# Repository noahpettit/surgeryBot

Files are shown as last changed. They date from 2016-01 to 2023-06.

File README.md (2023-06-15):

# surgeryBot
Code for motorized control of kopf 1900 stereotaxic  

key features:
- easily removable for cleaning / autoclaving
- adjustable gear ratio with simple, friction-fit parts
- even with motor mounted and gears engaged, you can still move stereotax manually (unlike some other motorized sterotaxes). 
- stepper is self-calibrating based on encoder feedback
- ~1um accuracy (same as encoder readout)
- closed-loop control using either computer and/or microcontroller
- matlab library for easy integration into more complex control programs (such as automated surgery bot).

# Hardware
The basic hardware consists of a laser-cut mount(s) to drive one or more axes with nema 17 stepper motors.






## Stepper Motor Mount


Mount hardware laser cut from 1/4" acrylic. The gears that fit onto the knob are friction fit so adjust the internal diameter if neccessary (or add tape/ shim) to get a tight fit so that they don't slip. 

laser-cutter ready designs in https://github.com/noahpettit/surgeryBot/blob/master/Hardware/Stepper_mount/StepperMountAndGears_v2_lasercutter.pdf 

I think all screws are M3, so non-through holes need to be M3 tapped.

## Stepper motor

I believe I used this one: https://www.adafruit.com/product/324
Although slightly more powerful motors would probably be better, especially if your axis is a bit sticky. 

## Stepper motor driver

I used this: https://www.adafruit.com/product/1438 with an arduino uno. It needs to have its own power source that provides enough current to drive whatever steppers you are using. I also STRONGLY suggest having an inline power switch so that you can quickly turn off the system if something goes wrong. The last thing you want is for a bug in your code to cause the stepper motor to drive the arm too fast or beyond its limits and potentially damage it. If using long-term, consider incorporating limit switches.

## Cables
 - computer to arduino USB
 - power cable for stepper motor driver
 - wires to connect stepper with stepper motor driver
 - serial to serial or serial to USB to connect accurite with computer and get position read-out

# Software

The basic idea is thatyou initialize a matlab surgery object that handles communication with the hardware (through serial communication). it reads in position data from the accurite and directs the stepper to move forwards or backwards. 
The object can self-calibrate using encoder feedback to get um per step of the stepper, and then also operates in closed-loop during execution to ensure that targets are reached and not exceeded. 

Test all the code yourself and use at your own risk! 

Using that object as a simple interface with the harware, you can write matlab scripts that contain cells that you might execute during particular stages of your surgery (see Protocols folder for an example).

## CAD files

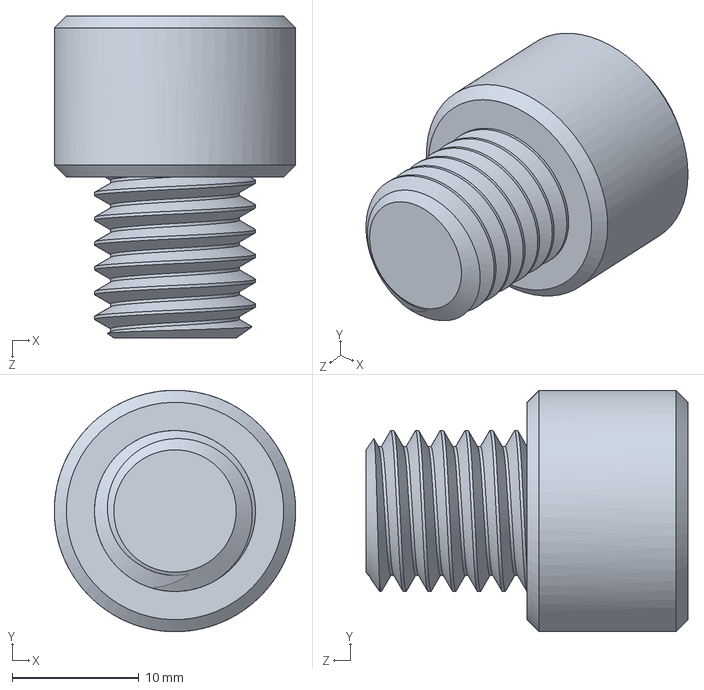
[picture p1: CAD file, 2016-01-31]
95868A407.SLDPRT
19.1 x 19.0 x 25.4 mm

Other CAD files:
Hardware/Stepper_mount/cameraMount_USBPluggableKopf.dwg
Hardware/Stepper_mount/stereotax_stepperMount3.dwg
Hardware/Stepper_mount/usbCameraMount2.dwg
Hardware/Stepper_mount/cameraMount_BaslerKopf.dwg
Hardware/Stepper_mount/stereotax_gearMount4_gearKerfAdjusted.dwg
Hardware/Stepper_mount/stereotax_stepperMount3_1_1648782924_7599.sv$.dwg
Hardware/Stepper_mount/stereotax_gearMount2.dwg
Hardware/Stepper_mount/stereotax_gearMount4.dwg
Hardware/Stepper_mount/stereotax_stepperMount2.dwg
Hardware/Stepper_mount/stereotax_gearMount3.dwg
Hardware/Stepper_mount/usbCameraMount3.dwg
Hardware/Stepper_mount/stereotax_gearMount2_1_446280268_4971.sv$.dwg
Hardware/Stepper_mount/stereotax_gearMount.dwg
Hardware/Stepper_mount/stereotax_stepperMount.dwg
Hardware/Stepper_mount/StepperMountAndGears_v2.dwg
Hardware/Stepper_mount/gear.iam

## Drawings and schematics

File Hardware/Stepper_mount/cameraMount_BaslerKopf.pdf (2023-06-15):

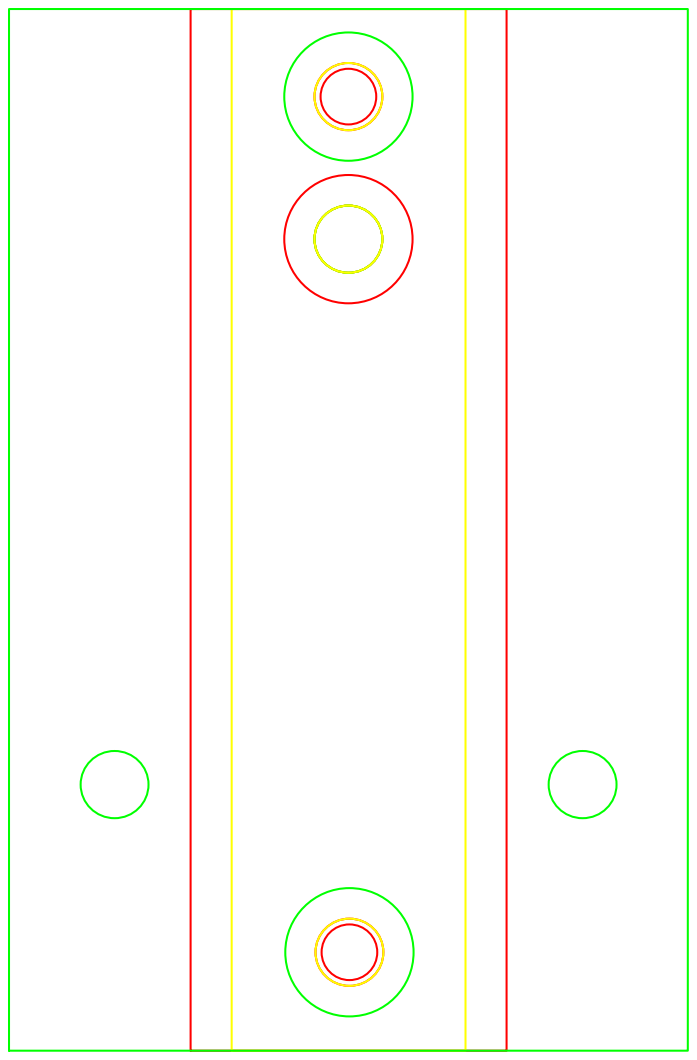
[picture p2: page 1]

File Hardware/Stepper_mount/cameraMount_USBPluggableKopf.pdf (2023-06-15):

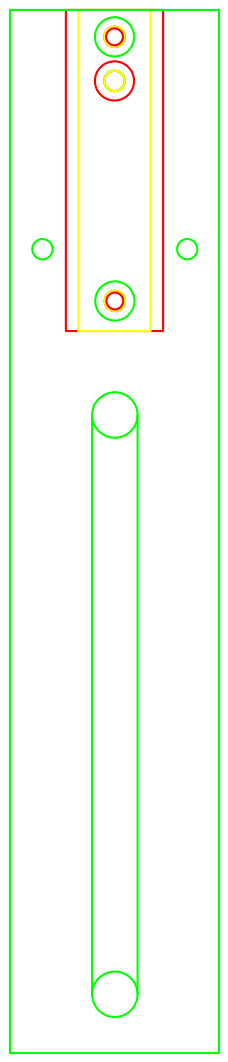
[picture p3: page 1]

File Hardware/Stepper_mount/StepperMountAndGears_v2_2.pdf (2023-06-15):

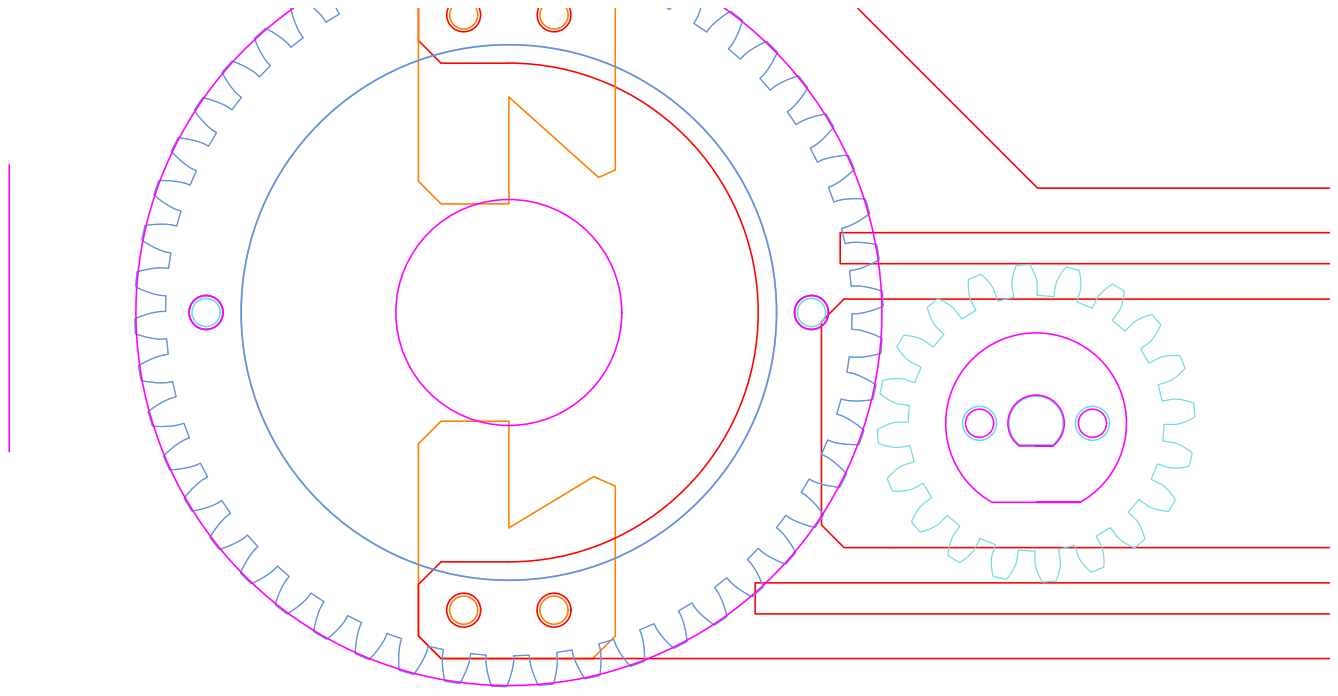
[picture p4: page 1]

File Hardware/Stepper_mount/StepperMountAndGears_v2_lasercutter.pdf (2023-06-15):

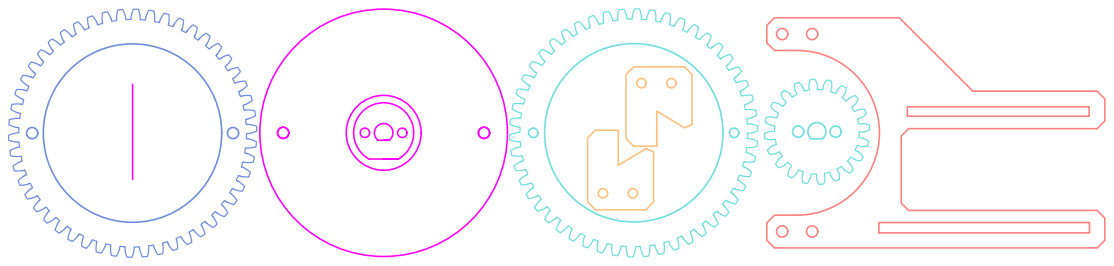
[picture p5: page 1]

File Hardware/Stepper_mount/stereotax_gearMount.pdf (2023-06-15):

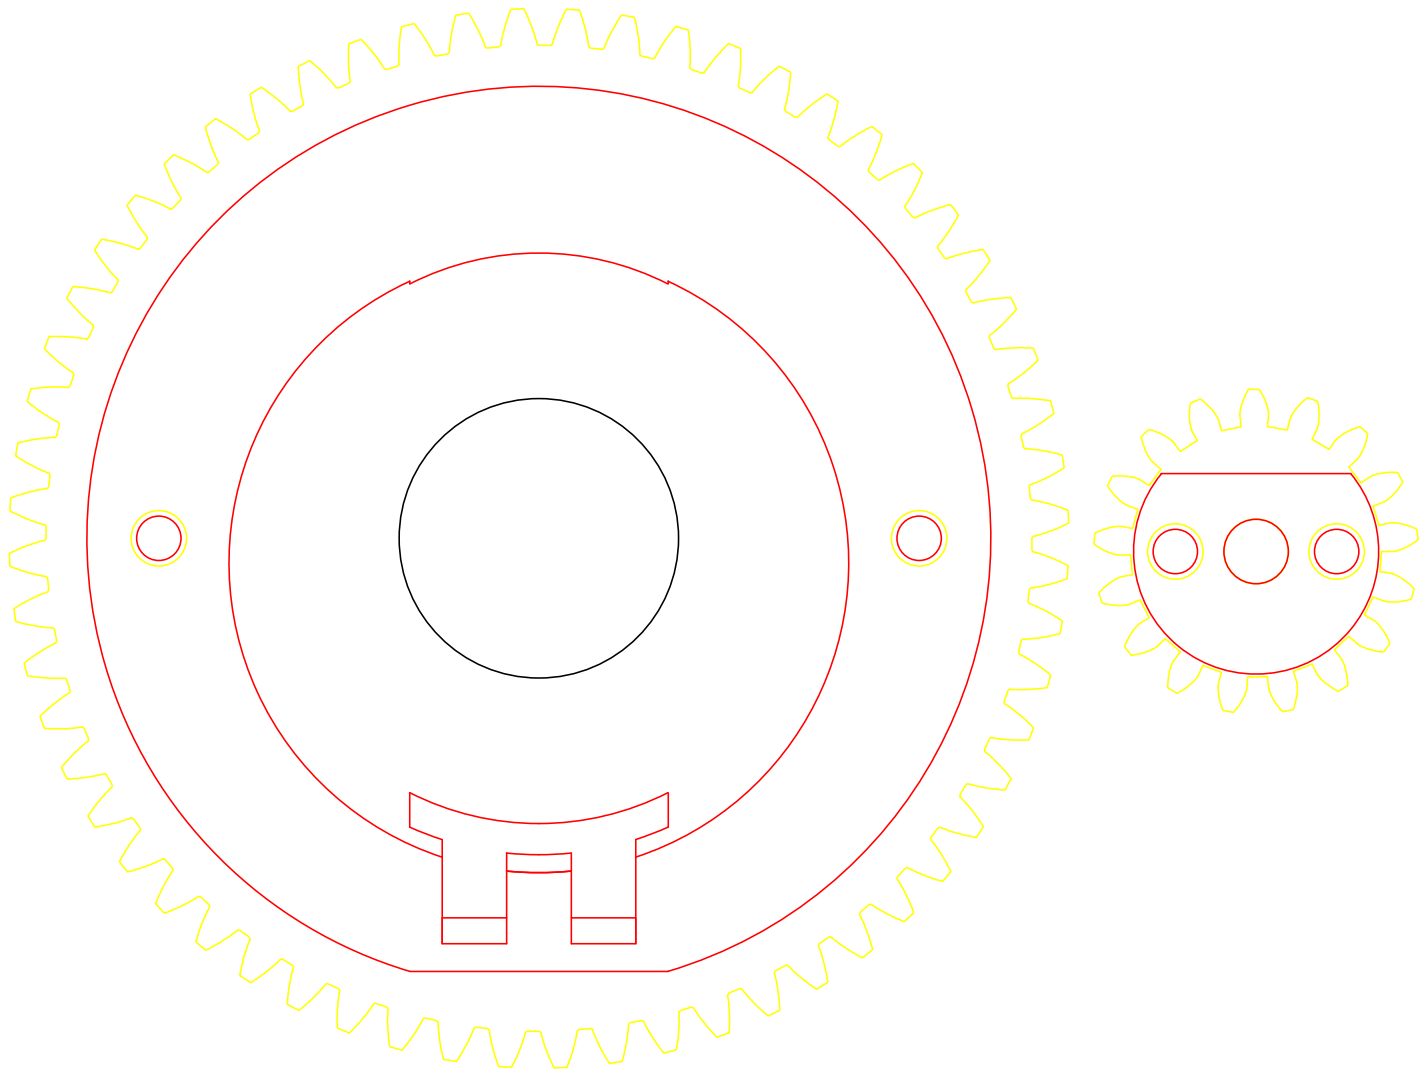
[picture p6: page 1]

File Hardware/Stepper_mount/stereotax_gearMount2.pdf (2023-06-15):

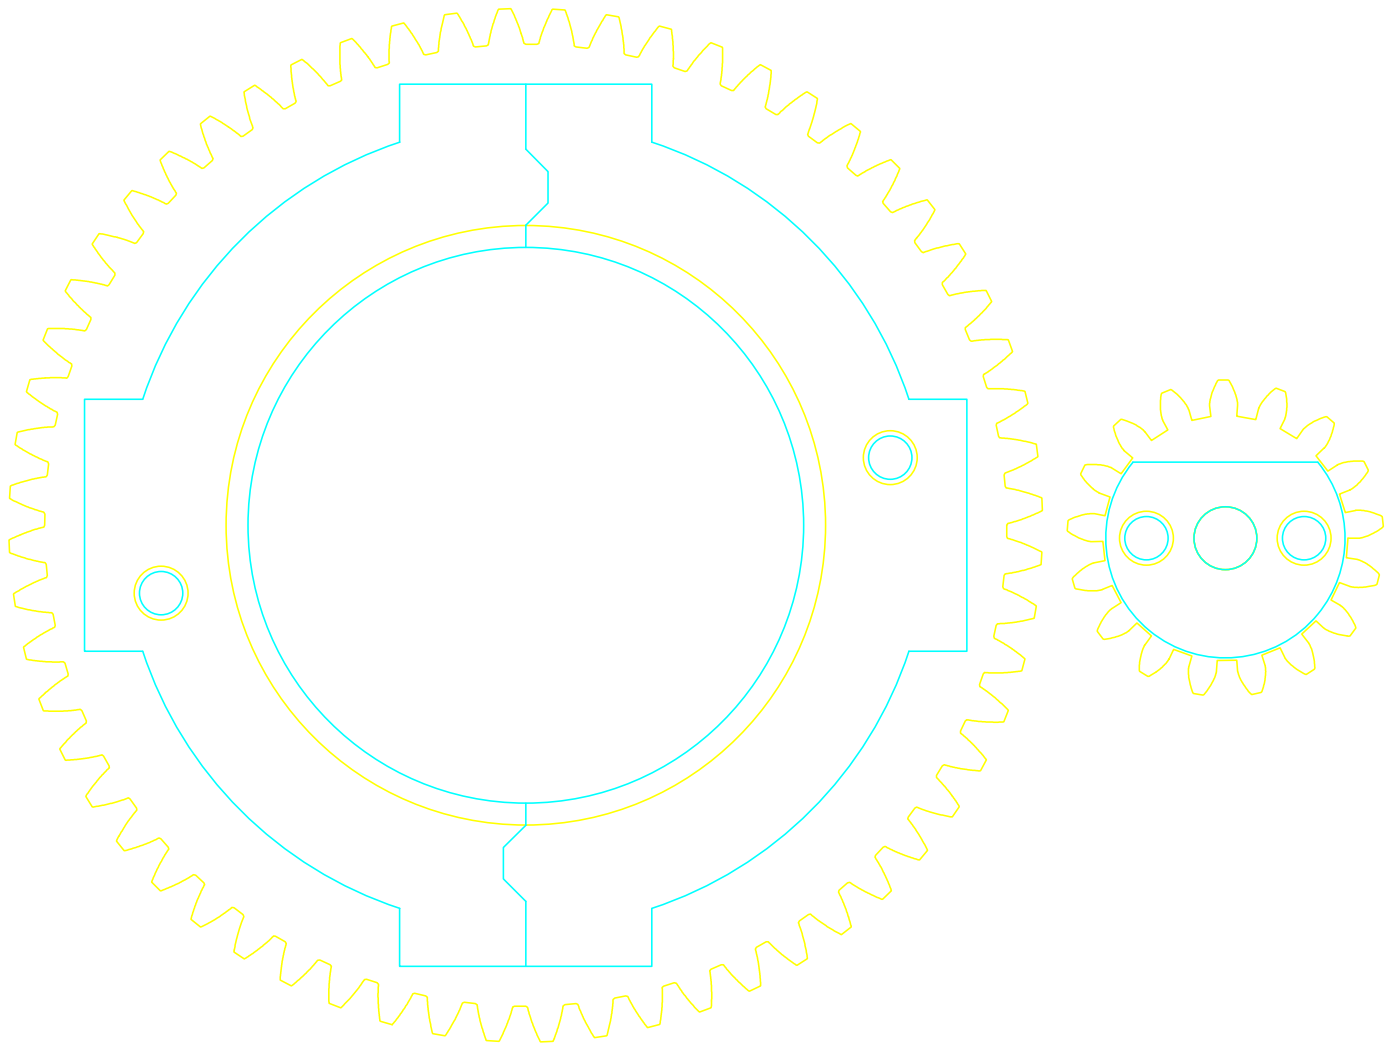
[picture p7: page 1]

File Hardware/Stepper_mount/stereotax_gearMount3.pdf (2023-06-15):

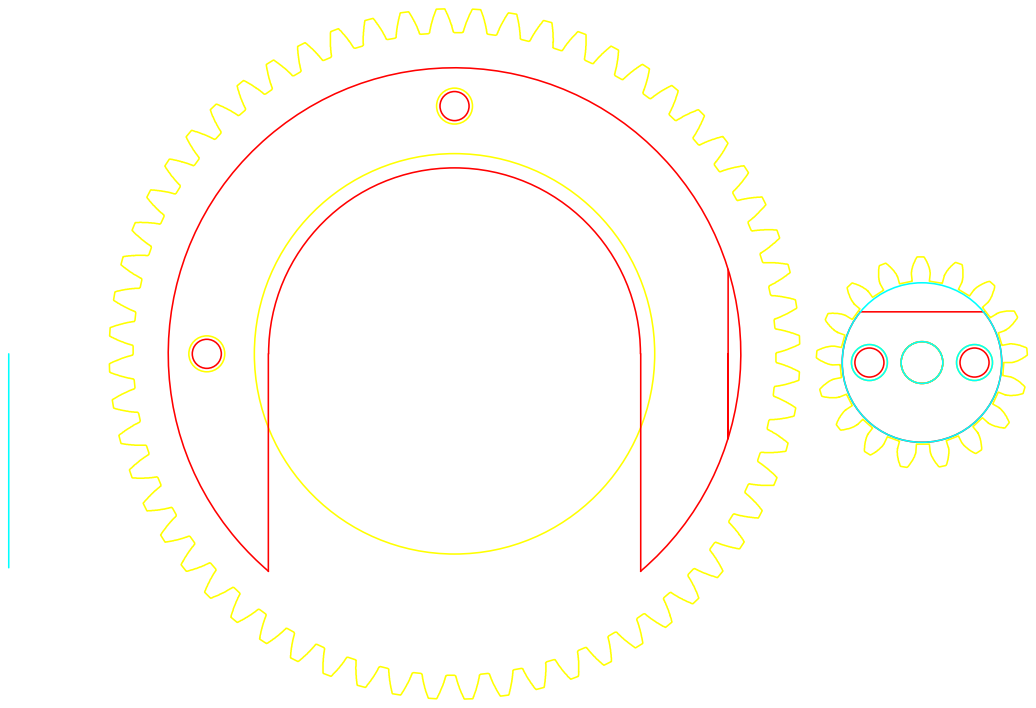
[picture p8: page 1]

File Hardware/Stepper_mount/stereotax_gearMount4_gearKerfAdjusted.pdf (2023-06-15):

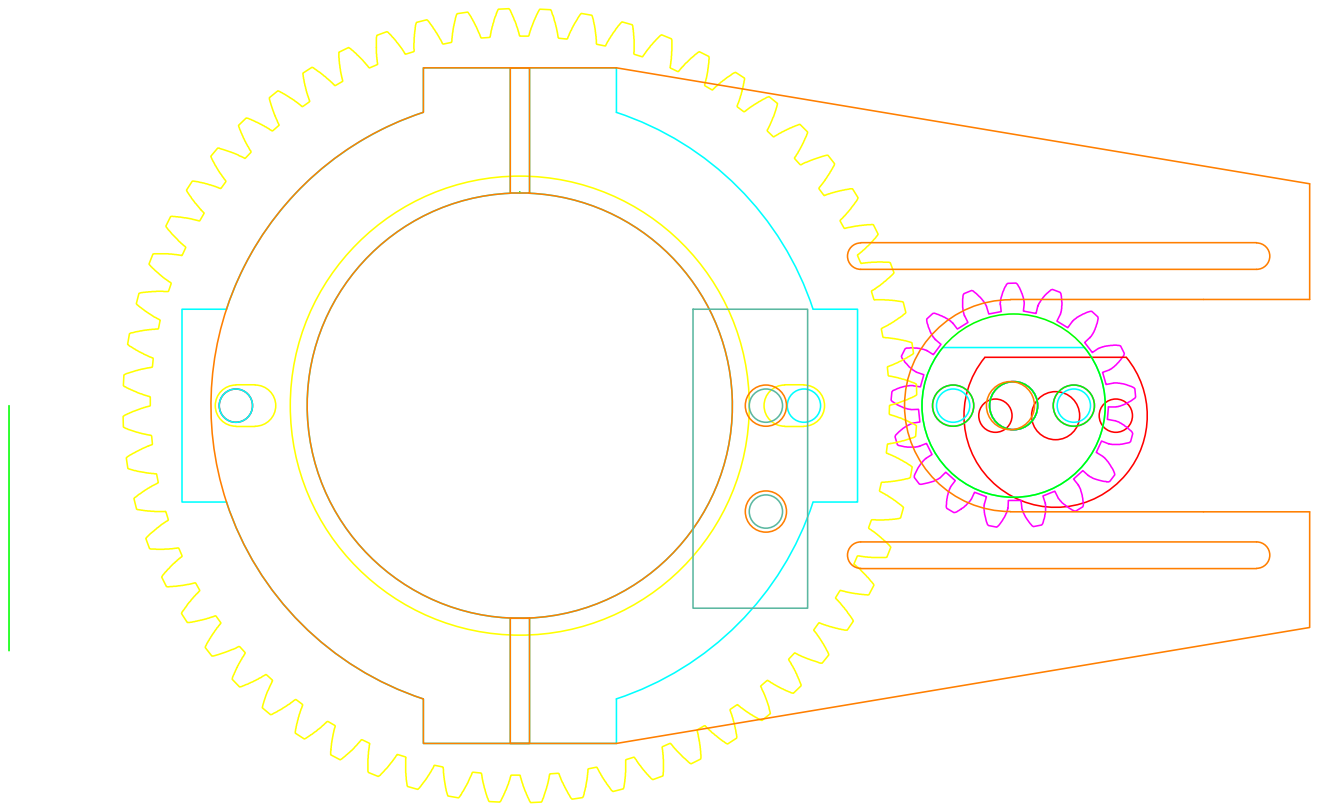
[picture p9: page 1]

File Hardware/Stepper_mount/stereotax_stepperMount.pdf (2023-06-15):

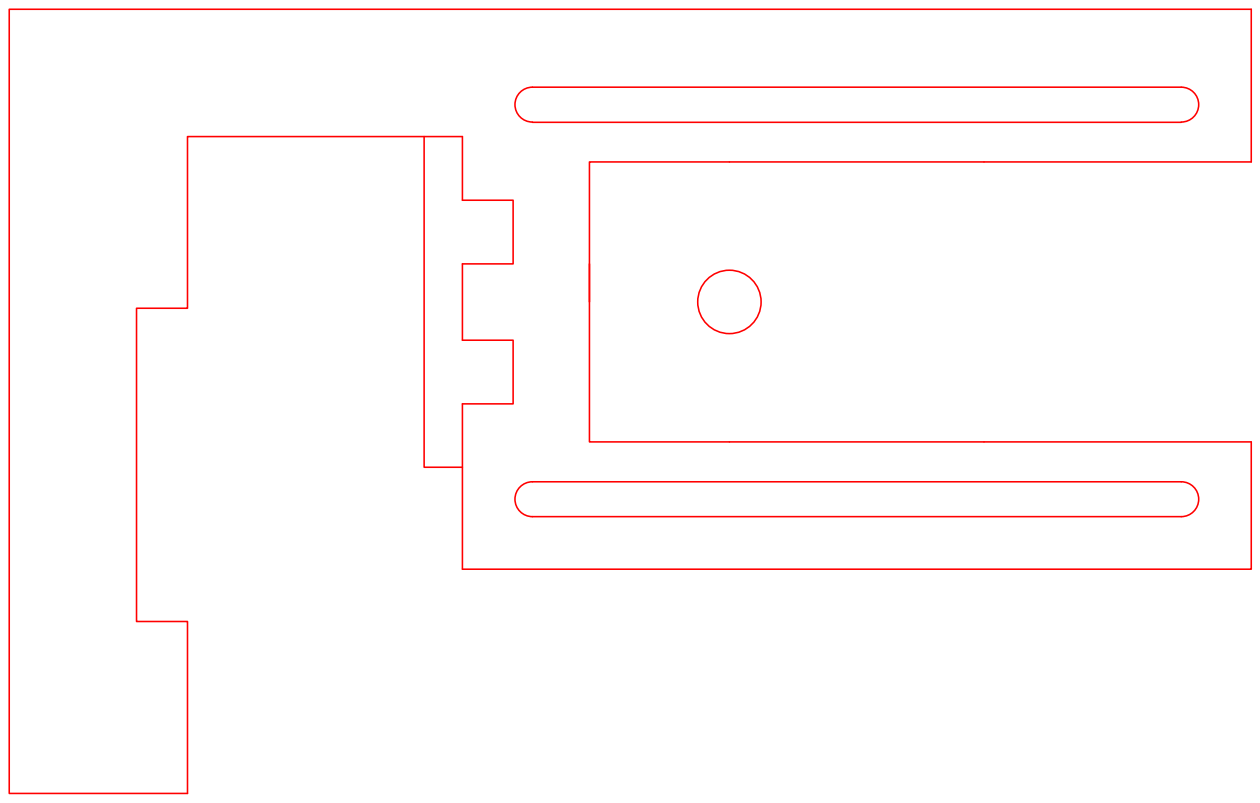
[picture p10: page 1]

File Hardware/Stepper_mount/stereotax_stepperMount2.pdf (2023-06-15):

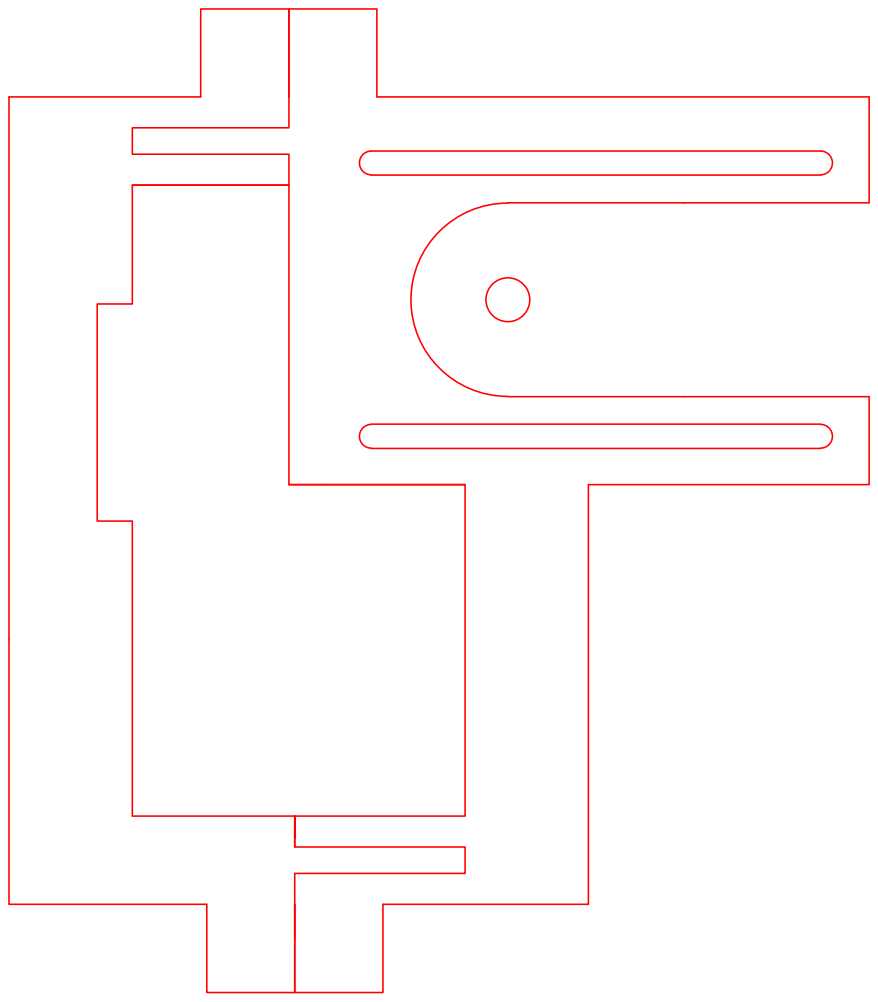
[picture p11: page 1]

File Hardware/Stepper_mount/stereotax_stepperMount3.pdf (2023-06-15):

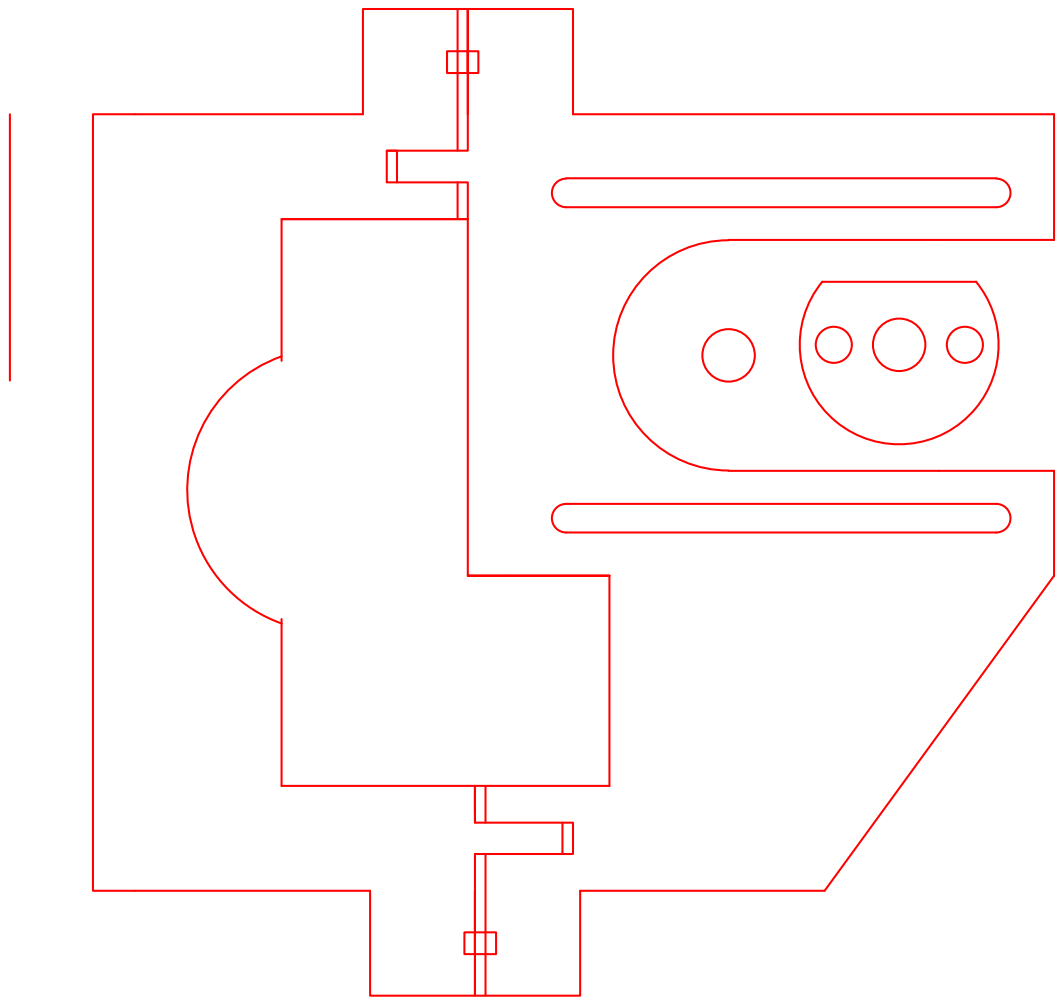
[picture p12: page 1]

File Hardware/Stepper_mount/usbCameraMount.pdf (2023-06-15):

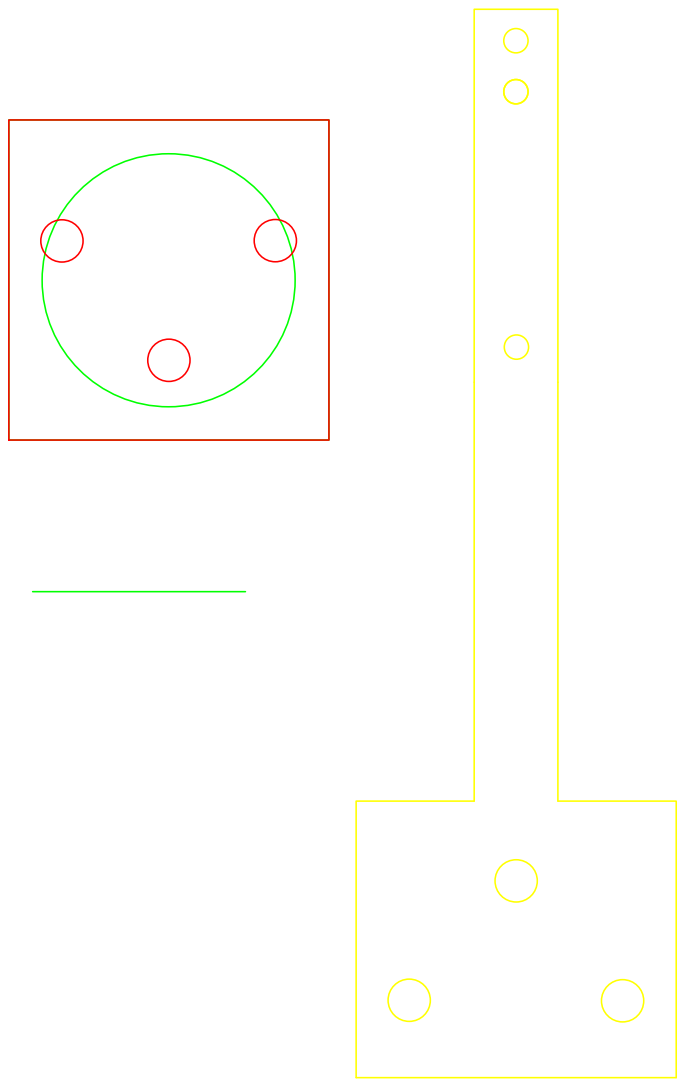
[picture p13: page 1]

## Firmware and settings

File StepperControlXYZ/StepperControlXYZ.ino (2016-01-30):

/* 
This is a test sketch for the Adafruit assembled Motor Shield for Arduino v2
It won't work with v1.x motor shields! Only for the v2's with built in PWM
control

For use with the Adafruit Motor Shield v2 
---->	http://www.adafruit.com/products/1438
*/


#include <Wire.h>
#include <Adafruit_MotorShield.h>
#include "utility/Adafruit_PWMServoDriver.h"

// Create the motor shield object with the default I2C address
Adafruit_MotorShield AFMS1 = Adafruit_MotorShield(); 
Adafruit_MotorShield AFMS2 = Adafruit_MotorShield(0x61); 
// Or, create it with a different I2C address (say for stacking)
// Adafruit_MotorShield AFMS = Adafruit_MotorShield(0x61); 

// Connect a stepper motor with 200 steps per revolution (1.8 degree)
// to motor port #2 (M3 and M4)
Adafruit_StepperMotor *myStepper1 = AFMS1.getStepper(200, 1);
Adafruit_StepperMotor *myStepper2 = AFMS1.getStepper(200, 2);
Adafruit_StepperMotor *myStepper3 = AFMS2.getStepper(200, 2);

// for merging two bytes into a 16 bit int - used for 
union u_tag {
    byte b[2];
    int ival;
} u;

// intialize stepper variables

int motorN = 1; // stepper motor number (typically 1 = x, 2 = y, 3 = z);
int stepStyle = 1; // step type
int stepperDir = 0; // direction of the stepper (can be 1 or 0)
int stepperSteps = 0; // number of steps to take
int stepperSpeed = 0; // speed of the stepper in rpm 
uint8_t styleStrings[] = {SINGLE, DOUBLE, INTERLEAVE, MICROSTEP};
uint8_t dirStrings[] = {BACKWARD, FORWARD};

void setup() {
  Serial.begin(9600);           // set up Serial library at 9600 bps
  //Serial.println("Stepper test!");

  AFMS1.begin();  // create with the default frequency 1.6KHz
  AFMS2.begin(); // start second shield
  //AFMS.begin(1000);  // OR with a different frequency, say 1KHz
  
  // change the ic2 clock to 400 KHz - WHY??
  TWBR = ((F_CPU /400000l) - 16) / 2;

  // set all motors to a default speed of 10 rpm
  myStepper1->setSpeed(10); // 10 rpm  
  myStepper2->setSpeed(10); // 10 rpm 
  myStepper3->setSpeed(10); // 10 rpm  
  
}

void loop() {

  // read in info from the serial port

    if (Serial.available() > 5) {
      // matlab will write 6 bytes to the serial port:
      // 1st byte: motor number 
      motorN = Serial.read();
      // 2nd byte: stepper direction
      stepperDir = Serial.read(); // 1 is forward, 0 is backwards
      // 3rd byte: stepper speed
      stepperSpeed = Serial.read();
      // 4th byte: step type (1: SINGLE, 2: DOUBLE, 3: INTERLEAVE, 4: MICROSTEP)
      stepStyle = Serial.read();
      // 5th and 6th byte: number of steps to make
      u.b[0] = Serial.read();
      u.b[1] = Serial.read();
      // merge two bytes into 16 bit int for n steps
      stepperSteps = u.ival; 
      
      

      // drive the motor
      if (motorN == 1) {
      myStepper1->setSpeed(stepperSpeed);
      myStepper1->step(stepperSteps, dirStrings[stepperDir],styleStrings[stepStyle-1]);
      } else if (motorN == 2) {
      myStepper2->setSpeed(stepperSpeed);
      myStepper2->step(stepperSteps, dirStrings[stepperDir],styleStrings[stepStyle-1]);  
      } else if (motorN == 3) {
      myStepper3->setSpeed(stepperSpeed);
      myStepper3->step(stepperSteps, dirStrings[stepperDir],styleStrings[stepStyle-1]);
      } else {
      // do nothing
      }
      
  }

  
}

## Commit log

2016-01-31 Class def update
    [95868A407.SLDPRT]
2023-06-15 Added stepper mount hardware design files
    [StepperMountAndGears_v2.dwg, cameraMount_BaslerKopf.dwg, cameraMount_USBPluggableKopf.dwg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]
